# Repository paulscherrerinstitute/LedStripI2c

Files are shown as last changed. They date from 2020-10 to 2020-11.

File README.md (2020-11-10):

# Bar-Graph Display Project

Display current pulse-ID on a LED-bar.
The LEDs are driven by PCA9955 LED controllers
and remote-controlled by I2C over a fiber
connection.

 - [kicad/](kicad/)

   Kicad design files; [schematics](kicad/ledstrip-sch.pdf) and pcb.

 - [hdl/](hdl/)

   vhdl code for driving the device from a FPGA
   ([documentation](hdl/README.md)).

 - [python/](python/)

   python scripts to drive the device from the USB/I2C
   adapter (for testing).

 - [PulseidExtractor/](PulseidExtractor/)

   submodule required to extract the pulse-id from an EVR320
   stream.

The LED device's I2C bus is accessible by three methods:

 - optical (light <-> logic 'low' on I2C bus) 
 - PMOD connector (1.5-3.3 V via i2c-transceiver) for
   connection, e.g., to a Zynq board.
 - USB-I2c bridge from host.

Note that in all use-cases power (5V, 350mA max.) must be
provided at the USB port (from host or USB wall-wart).

A mini-USB connector was deemed mechanically more stable than
micro-USB. USB-C would be an alternative.

Till Straumann, 10/2020.

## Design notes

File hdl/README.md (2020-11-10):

# LedStrip Firmware

Extract the pulse-ID from a data stream (input) that 
originates at an embedded EVR320 module (the EVR320
is not instantiated within this LedStrip module).
Drive two PCA9955 LED controllers over i2c to display
the pulse-ID as a binary number (LED bar).

## Features

The firmware implements the following features:

 - tosca2/TCSR compatible register interface
 - controllable LED brightness.
 - programmable I2C speed.
 - readback verification: the firmware reads the displayed
   value back and increments an error counter if the readback
   does not match the expected value (catch potential i2c errors).
 - support permanently lit 'marker' LEDs.
 - display pulse-ID as gray-encoded or binary number.
 - error/status counters.

## Register Map (Version 0)

All registers are 32-bit. The address given in this table is
the register index (= word-address), not a byte address:

| Register | Access | Function |
|---|---|---|
|  0 | RO | Version Register |
|  1 | R/W | Control Register |
|  2 | R/W | Marker/Mask |
|  3 | RO | I2C Arbitration Lost Counter |
|  4 | RO | I2C Write Not Acknowledged Counter |
|  5 | RO | Readback Error/Mismatch Counter |
|  6 | RO | Pulse-Id Sequence Error Counter |
|  7 | RO | Pulse-Id Watchdog Error Counter |
|  8 | RO | Display-update Trigger Counter |
|  9 | RO | Stream Synchronization Error Counter |

The control register provides the following functionality
(Defaults marked with 'G' can be changed by setting a VHDL generic)

| Bit Range| Default | Function |
|---|---|---|
| [31:24]  | set for 400kHz (G)| Clock divider for generating SCL (see below) |
| [23:20]  | 0 | Multiplexer to select update trigger |
| [18] | 1 (G) | Enable Marker. |
| [17] | 0 | Enable binary encoding of display (Gray-code otherwise)|
| [16] | 0 | Reset firmware block (held in reset while bit is set)  |
| [15:08]  | 255 | Brightness PWM setting for PCA9955 |
| [07:00]  | 128 | Brightness IREF current setting for PCA9955 |

### Version Register
The least-significant 4 bits of the version register define the version
of the register layout (version 0 described in this document).
The most-significant 28 bits optionally contain a (binary-encoded) git
hash (all-zero when unused).

### Clock Divider

The i2c SCL clock is derived from the bus clock fed into the firmware module.

    SCL_clock = Bus_clock / divider_value / 4

The divider value is computed from the corresponding 8 bits in the control register.
If the most-significant bit of the divider value is set then bits [7:0] define the
divider value verbatim, e.g.,

    0xC0 => divider value 0x40 => SCL freq. = bus-freq / 64 / 4

If the MSbit is clear then the divider is taken from a table of larger values (consult
the firmware sources for details).

### Trigger Multiplexer

The firmware has 16 inputs for (Evr-generated) triggers which can be used to decimate
the rate at which the display updates (useful for slow cameras). The multiplexer selects
one of these triggers. By default trigger #0 is permanently asserted 1 (which results in
the display updating every time a new pulse-ID streams out of the EVR) and trigger #1 is
permanently asserted 0 (which results in the display not updating).

### Marker

If the marker is enabled then the displayed pulse-ID is shifted left by one bit and ORed
with a mask (contents of register R2):

    displayed_pattern :=  (pulse_id << 1) | mask

This feature can be used to permanently light some 'marker' LEDs. If the marker is disabled
then register R2 is ignored.

### Encoding

The pulse-ID can be displayed in binary- or gray-encoding. The latter has obvious advantages
when capturing the display with a camera. If exposure-time overlaps the change of the pulse-ID
then the relative brightness of the changing LED confers some information about the timing of
the shutter. It also avoids any ambiguity of a not properly synchronized readout.

### Reset

While this bit is asserted the firmware block (including the i2c controller) is held in reset.
Note that the reset does not extend to the remote PCA9955 LED controllers.

### PWM and IREF

The PCA9955 supports controlling LED brightness by two (cumulative) methods: PWM at a frequency
of multiple kHz as well as modulating an analog current source. Both parameters can be programmed
in the control register.

*NOTE*: The i2c transactions required to change the brightness are interleaved with updating
        the pulse-ID.  I.e., if the pulse-ID does not update (e.g., because the trigger mux
        selects the permanently disabled trigger) then the brightness settings are not forwarded
        to the PCA9955 controllers either. Similarly, if the update rate is reduced then changes
        to the brightness take longer to be forwarded to the PCA9955 (after each pulse-ID update
        *one* brightness setting for *one* LED is transmitted, e.g., it takes 64 pulse-ID updates
        to forward the PWM and IREF to all 32 channels in the PCA9955 devices).

### Error counters

The counters keep track of

 - Lost i2c arbitrations. Because normally (i.e., unless the USB-i2c bridge or the PMOD connector
   are in active use) there are no other bus masters these errors are most likely caused by too
   high a SCL frequency or non-optimal filter settings (only tunable via generics). Try lowering
   the i2c SCL frequency.
 - Unacknowledged i2c transactions. This occurs most likely because the LedStrip hardware module
   is not connected or intermediate entities (e.g., GPIO ports) are not configured correctly.
 - Readback errors. The readback failed or readback data does not match the expected value (e.g.,
   because a glitch on the i2c bus). An unacknowledged transaction error also implies a readback
   error but the converse is not true.
 - Pulse-Id sequence errors. This counter is incremented when the difference between
   subsequently received pulse-ids is not 1.
 - Watchdog errors: Check that a new pulse-ID is received from the EVR stream within 12 ms
   (this timeout value is a generic setting).
 - Trigger counter: This counter increments when the display update is triggered (which
   may happen at a rate that is lower than the pulse-Id update rate if the update trigger
   inputs are used).
 - EVR Stream Synchronization Errors. Checks that all bytes corresponding to a pulse-ID are
   actually received from the EVR stream. 

The readback error counter can be used to ensure that all pulse-IDs have been propagated
correctly to the display hardware. The watchdog error counter can be used to verify that
pulse-Ids are received and the sequence error counter can be used to verify that the
received pulse-Ids are sequential.

## Firmware Module

The top level entity is defined in [LedStripTcsrWrapper.vhd](LedStripTcsrWrapper.vhd).

### Dependencies

The module requires the [PulseidExtractor](https://github.com/paulscherrerinstitute/PulseIdExtractor.git)
which is registered as a submodule.

### Generics

Most of the generics have reasonable default values but a value for the bus frequency must
be supplied by the user.

| Generic |Default Value| Description |
|---|---|---|
|  TCSR_CLOCK_FRQ_G | | Bus Frequency (Hz) |
|  DFLT_I2C_SCL_FRQ_G | 400.0E3 | Default SCL Frequency (Hz) |
|  PULSEID_OFFSET_G | 52 | Starting offset of pulse-id in EVR stream |
|  PULSEID_LENGTH_G |  8 | Size of pulse-id (in bytes) |
|  PULSEID_BIGEND_G | false | Representation in EVR stream (big- vs. little-endian)|
|  ASYNC_CLOCKS_G | true | Whether the bus- and evr-clocks are asynchronous |
|  I2C_ADDR_R_G | "0000101" | I2C (7-bit) address of RHS PCA9955 |
|  I2C_ADDR_L_G | "1101001" | I2C (7-bit) address of LHS PCA9955 |
|  I2C_SYNC_STAGES_G | 3 | How many synchronizer stages on SCL/SDA inputs |
|  I2C_DEBOUNCE_CYCLES_G | 10 | For how many bus-cycles to debounce SCL/SDA inputs |
|  NUM_LEDS_G | 30 | How many LEDs are physically loaded on the board |
|  DFLT_MARKER_ENABLE_G  | '1' | Default value of marker-enable bit in R0 |
|  PULSEID_WDOG_PER_MS_G | 12.0 | Pulse-Id watchdog timeout [ms]; disabled when 0.0 |
|  VERSION_G | x"000_0000" | Firmware Version ID (e.g., git-hash) |

*Note*: The i2c addresses of the PCA9955 controllers is defined by hardware straps on the board
        but there are *slightly different versions of the PCA9955* which interpret the strapping
        differently (PCA9955 vs. PCA9955B). Consult the KiCad schematics and hardware manuals for
        details.

### Ports

The module's ports are listed in the following table. Signals are in the clock-domain of the last
clock previously listed.

|  Signal | Type/Default | Description |
|---|---|---|
|  tcsrCLK  | in  std_logic |  Bus clock |
|  tcsrRST  | in  std_logic |  Synchronous reset|
|  tcsrADD  | in  std_logic_vector( 4 downto 2) |  (Word-) address  |
|  tcsrDATW | in  std_logic_vector(31 downto 0) |  Write data |
|  tcsrWE | in  std_logic_vector( 3 downto 0) |  Lane write-enable|
|  tcsrDATR | out std_logic_vector(31 downto 0) |  Read data |
|  tcsrWR | in  std_logic |  Write strobe |
|  tcsrRD | in  std_logic |  Read strobe |
|  tcsrACK  | out std_logic |  ACK (always '1') |
|  tcsrERR  | out std_logic |  ERR (always '0') |
|  sclInp | in  std_logic |  i2c SCL input |
|  sclOut | out std_logic |  i2c SCL output |
|  sdaInp | in  std_logic |  i2c SDA input |
|  sdaOut | out std_logic |  i2c SDA output |
|  evrClk | in  std_logic |  EVR clock |
|  evrStream| in  EvrStreamType |  EVR data stream  |
|  ledTrig  | in  std_logic_vector(15 downto 0) := x"0001" |  Update trigger |

### Constraints

If the bus- and evr- clocks are asynchronous then some details need to be
considered: There are two clock-domain crossings in the module

 - The pulse-ID is taken from the `evrClk` into the `tcsrCLK` domain. If the
   `ASYNC_CLOCKS_G` generic is set to `true` then a synchronizer stage is
   instantiated which synchronizes and delays the pulse-ID strobe signal until
   the (parallel) pulse-ID has stabilized and can be safely read into the `tcslCLK`
   domain. A proper `DATAPATHONLY` constraint should be defined:

       INST "*B_PulseIdExtractor.U_GetPid/rClk_pulseid_*" TNM = LEDSTRIP_PULSEID_REG;
       TIMESPEC TS_<name> = FROM "LEDSTRIP_PULSEID_REG" TO <tnm_of_bus_clock_domain> <delay> DATAPATHONLY;

   The user has to provide proper definitions for the items in angled-brackets. The
   maximum datapath delay should limit any delay to less than the two bus-cycles delay
   of the strobe signal. Some margin needs to allocated to possible clock skew!

 - The trigger multiplexer setting crosses from the `tcsrCLK` into the `evrCLK` domain.
   Assuming that this setting remains mostly stable and we don't care about glitches
   during a change of the mux setting we can set a false-path:

       INST "*B_PulseIdExtractor.trgMuxEvr_*"          TNM = LEDSTRIP_MUX_REG;
       TIMESPEC TS_<name> = FROM <tnm_of_bus_clock_domain> TO "LEDSTRIP_MUX_REG" TIG;

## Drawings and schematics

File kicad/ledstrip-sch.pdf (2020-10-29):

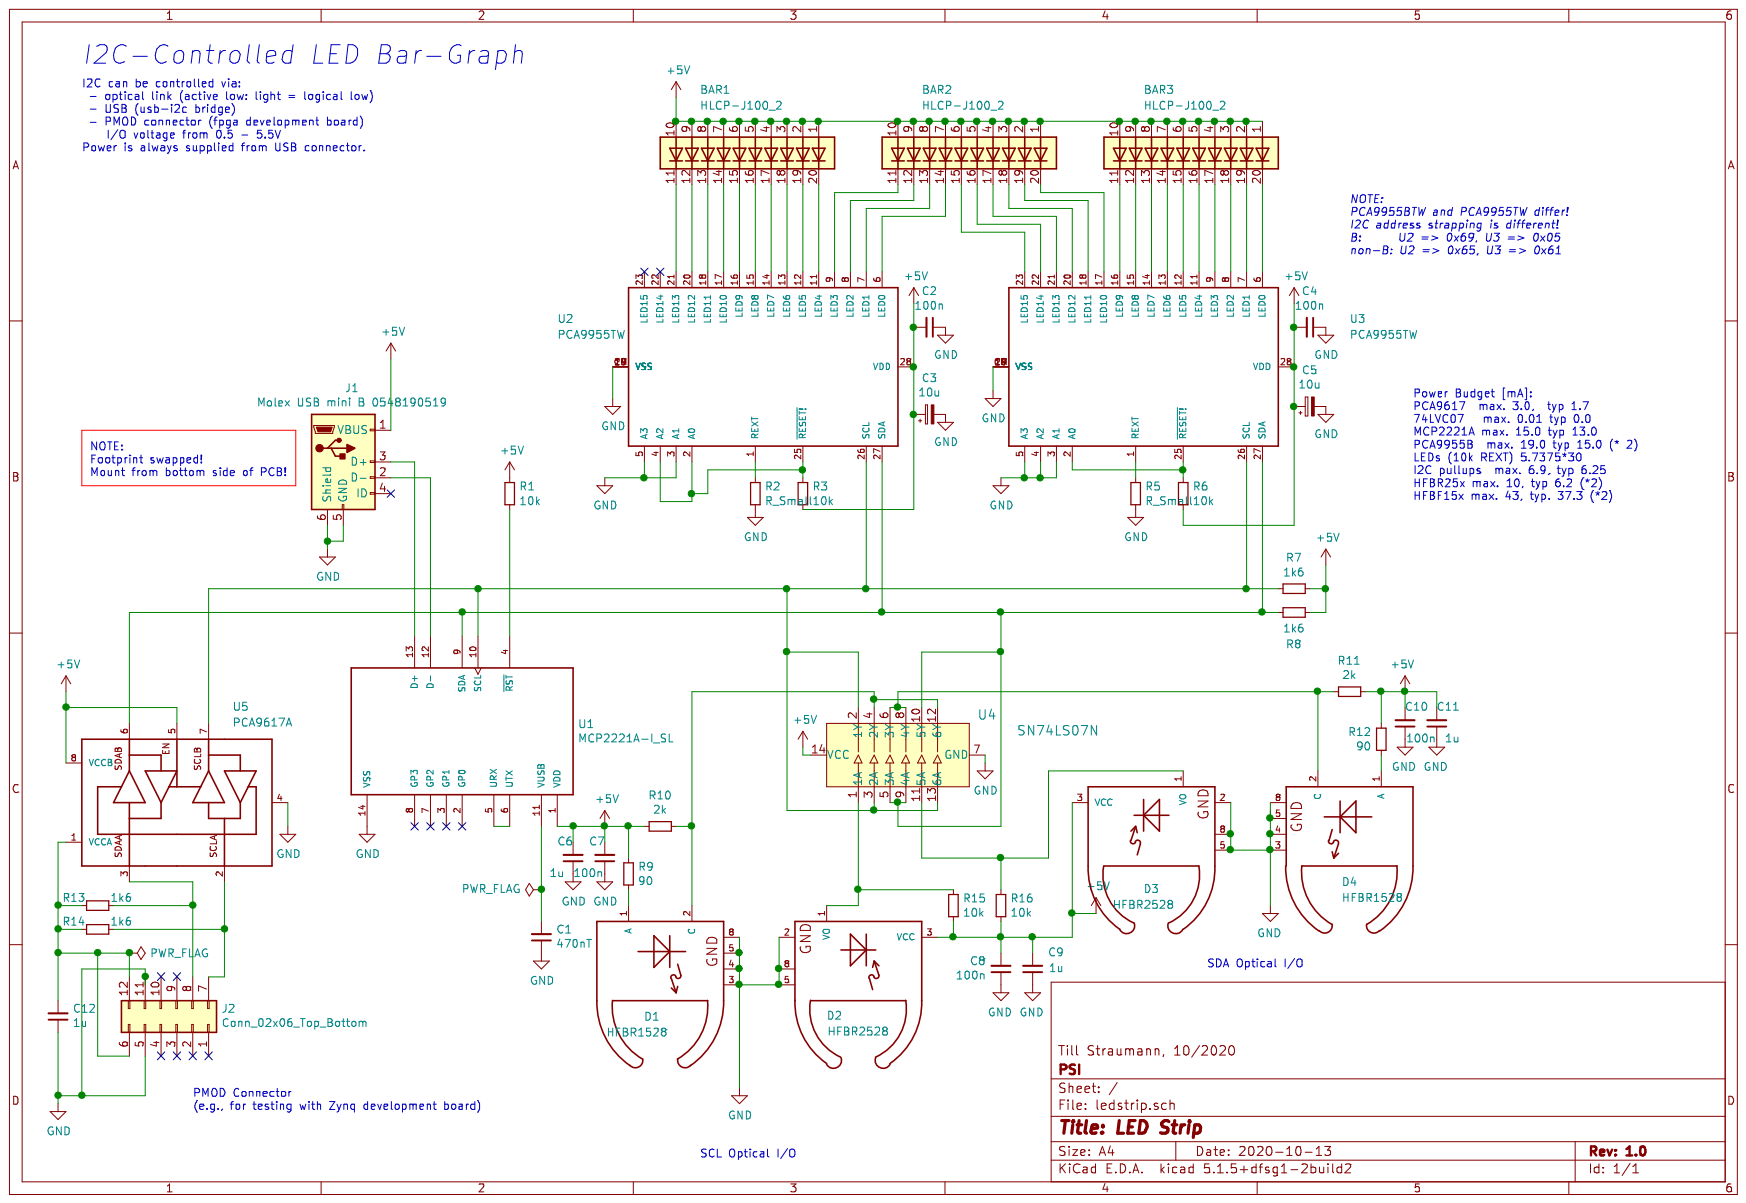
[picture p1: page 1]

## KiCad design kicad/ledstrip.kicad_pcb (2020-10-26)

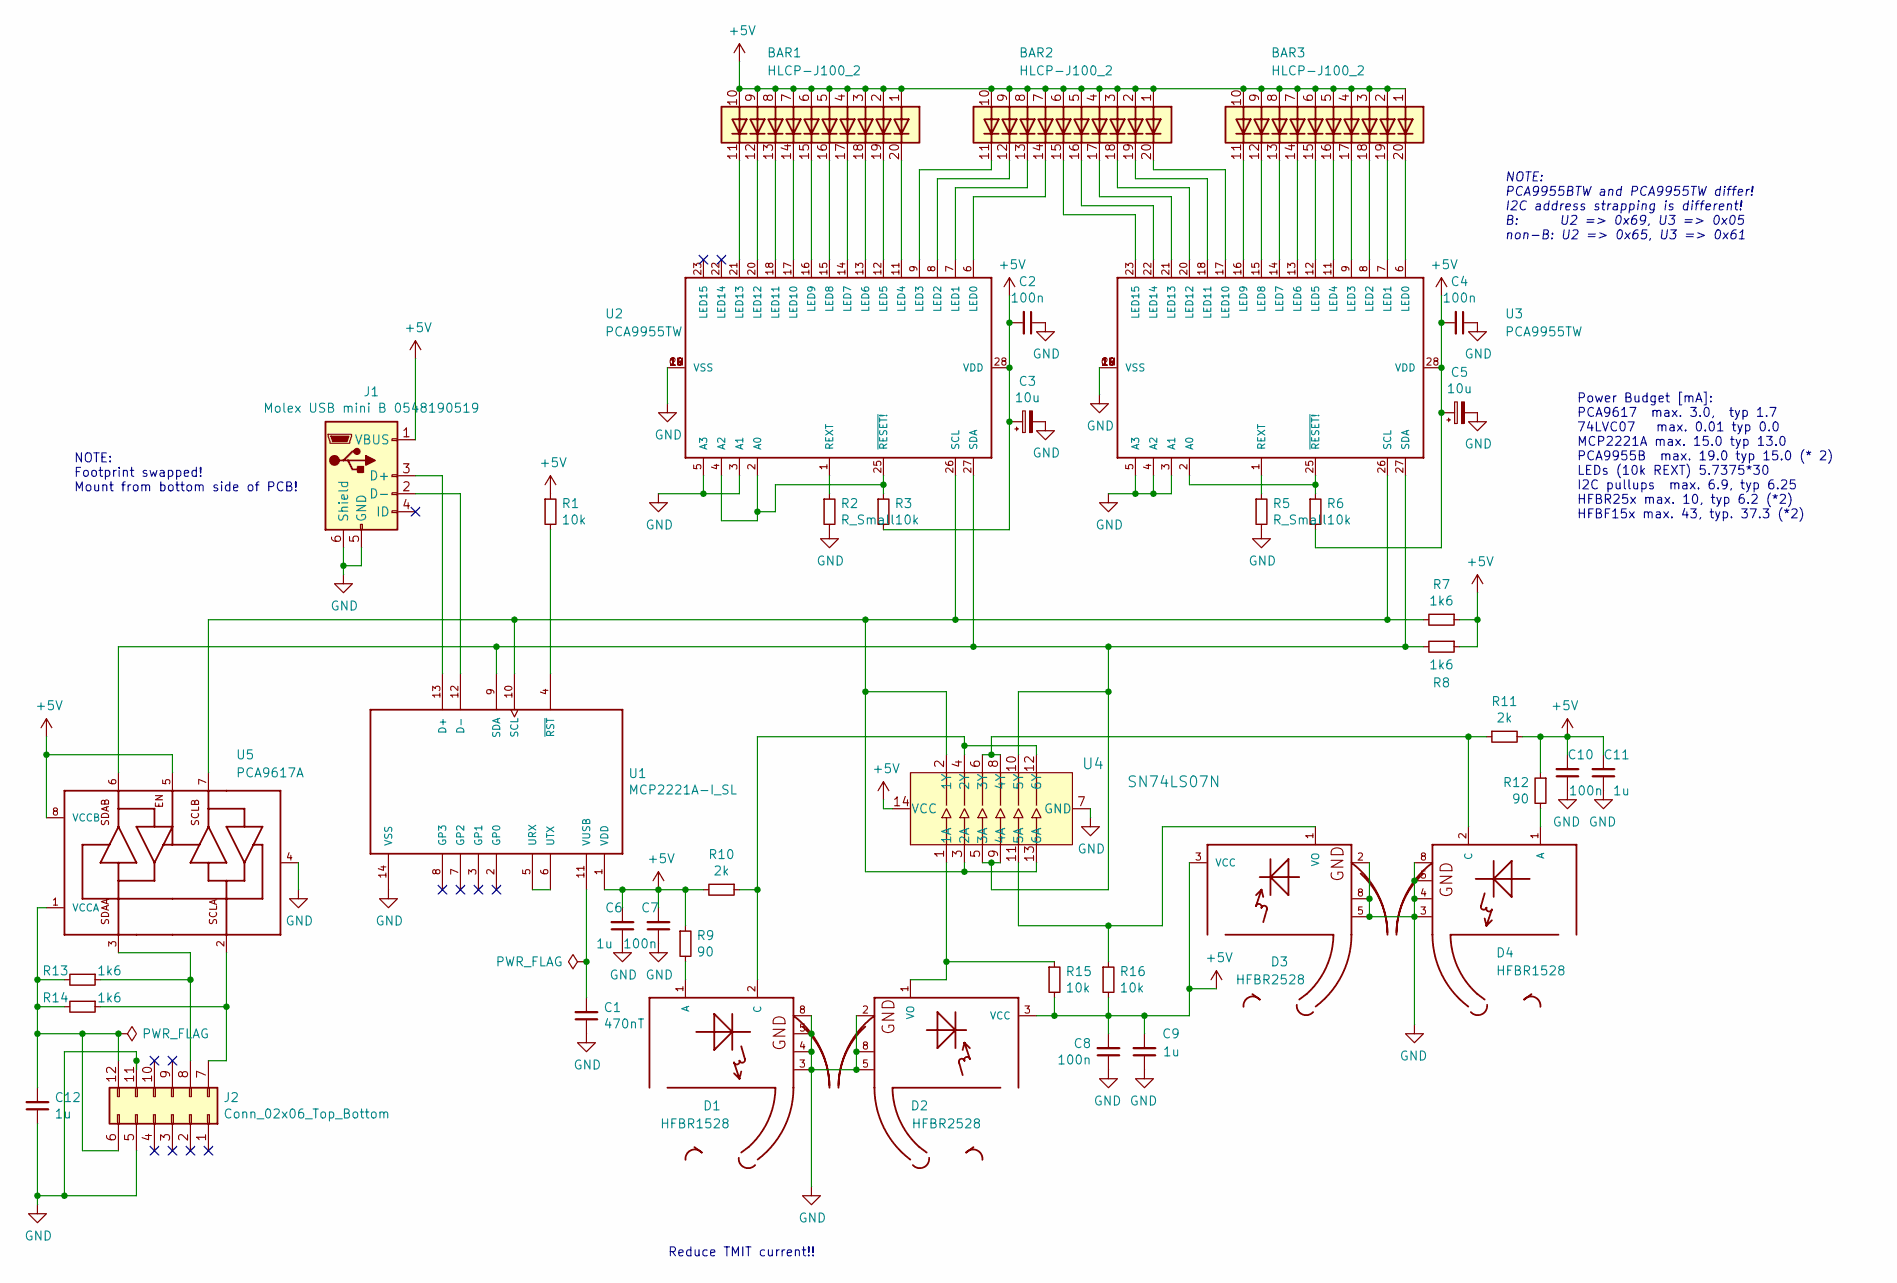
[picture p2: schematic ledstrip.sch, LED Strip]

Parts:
BAR1, BAR2, BAR3: HLCP-J100_2; HLCP-J100
C1: 470nT; C_0805_2012Metric
C2, C4, C7, C8, C10: 100n; C_0603_1608Metric
C3, C5: 10u; CP_EIA-3216-10_Kemet-I
C6, C9, C11, C12: 1u; C_0805_2012Metric
D1, D4: HFBR1528; HFBR25XX
D2, D3: HFBR2528; HFBR25XX
J1: Molex USB mini B 0548190519; USB_Mini_B_Female_548190519
J2: Conn_02x06_Top_Bottom; PMOD_PinHeader_2x06_P2.54mm_Horizontal
R1, R3, R6, R15, R16: 10k; R_0603_1608Metric
R2, R5: R_Small; R_0603_1608Metric
R7, R8, R13, R14: 1k6; R_0603_1608Metric
R9, R12: 90; R_1206_3216Metric
R10, R11: 2k; R_0603_1608Metric
U1: MCP2221A-I_SL; SOIC127P600X175-14N
U2, U3: PCA9955TW; SOT1172-2
U4: SN74LS07N; SOIC-14_3.9x8.7mm_P1.27mm; MPN SN74LS07N; Digi-Key_PN 296-1629-5-ND
U5: PCA9617A; TSSOP-8_W3mm

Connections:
+5V: BAR1.1 (A), BAR1.2 (A), BAR1.3 (A), BAR1.4 (A), BAR1.5 (A), BAR1.6 (A), BAR1.7 (A), BAR1.8 (A), BAR1.9 (A), BAR1.10 (A), BAR2.1 (A), BAR2.2 (A), BAR2.3 (A), BAR2.4 (A), BAR2.5 (A), BAR2.6 (A), BAR2.7 (A), BAR2.8 (A), BAR2.9 (A), BAR2.10 (A), BAR3.1 (A), BAR3.2 (A), BAR3.3 (A), BAR3.4 (A), BAR3.5 (A), BAR3.6 (A), BAR3.7 (A), BAR3.8 (A), BAR3.9 (A), BAR3.10 (A), C2.2, C3.1, C4.2, C5.1, C6.2, C7.2, C8.2, C9.2, C10.2, C11.2, D2.3 (VCC), D3.3 (VCC), J1.1 (VBUS), R1.1, R3.2, R6.2, R7.1, R8.1, R9.1, R10.2, R11.2, R12.1, R15.2, R16.2, U1.1 (VDD), U2.28 (VDD), U3.28 (VDD), U4.14 (VCC), U5.5, U5.8 (VCCB)
GND: C1.1, C2.1, C3.2, C4.1, C5.2, C6.1, C7.1, C8.1, C9.1, C10.1, C11.1, C12.1, D1.3, D1.4, D1.5, D1.8, D2.2, D2.5, D2.8, D3.2, D3.5, D3.8, D4.3, D4.4, D4.5, D4.8, J1.5 (GND), J1.6 (Shield), J2.5, J2.11, R2.2, R5.2, U1.14 (VSS), U2.3 (A1), U2.5 (A3), U2.10 (VSS), U2.19 (VSS), U2.24 (VSS), U2.CM (VSS), U3.3 (A1), U3.4 (A2), U3.5 (A3), U3.10 (VSS), U3.19 (VSS), U3.24 (VSS), U3.CM (VSS), U4.7 (GND), U5.4
unnamed: BAR1.11 (K), U2.21 (LED13)
unnamed: BAR1.12 (K), U2.20 (LED12)
unnamed: BAR1.13 (K), U2.18 (LED11)
unnamed: BAR1.14 (K), U2.17 (LED10)
unnamed: BAR1.15 (K), U2.16 (LED9)
unnamed: BAR1.16 (K), U2.15 (LED8)
unnamed: BAR1.17 (K), U2.14 (LED7)
unnamed: BAR1.18 (K), U2.13 (LED6)
unnamed: BAR1.19 (K), U2.12 (LED5)
unnamed: BAR1.20 (K), U2.11 (LED4)
unnamed: BAR2.11 (K), U2.9 (LED3)
unnamed: BAR2.12 (K), U2.8 (LED2)
unnamed: BAR2.13 (K), U2.7 (LED1)
unnamed: BAR2.14 (K), U2.6 (LED0)
unnamed: BAR2.15 (K), U3.23 (LED15)
unnamed: BAR2.16 (K), U3.22 (LED14)
unnamed: BAR2.17 (K), U3.21 (LED13)
unnamed: BAR2.18 (K), U3.20 (LED12)
unnamed: BAR2.19 (K), U3.18 (LED11)
unnamed: BAR2.20 (K), U3.17 (LED10)
unnamed: BAR3.11 (K), U3.16 (LED9)
unnamed: BAR3.12 (K), U3.15 (LED8)
unnamed: BAR3.13 (K), U3.14 (LED7)
unnamed: BAR3.14 (K), U3.13 (LED6)
unnamed: BAR3.15 (K), U3.12 (LED5)
unnamed: BAR3.16 (K), U3.11 (LED4)
unnamed: BAR3.17 (K), U3.9 (LED3)
unnamed: BAR3.18 (K), U3.8 (LED2)
unnamed: BAR3.19 (K), U3.7 (LED1)
unnamed: BAR3.20 (K), U3.6 (LED0)
unnamed: C1.2, U1.11 (VUSB)
unnamed: C12.2, J2.6, J2.12, R13.2, R14.2, U5.1 (VCCA)
unnamed: D1.1 (A), R9.2
unnamed: D1.2 (C), R10.1, U4.4 (2Y), U4.12 (6Y)
unnamed: D2.1 (VO), R15.1, U4.1 (1A)
unnamed: D3.1 (VO), R16.1, U4.11 (5A)
unnamed: D4.1 (A), R12.2
unnamed: D4.2 (C), R11.1, U4.6 (3Y), U4.8 (4Y)
unnamed: J1.2 (D-), U1.12 (D-)
unnamed: J1.3 (D+), U1.13 (D+)
unnamed: J2.7, R14.1, U5.2
unnamed: J2.8, R13.1, U5.3
unnamed: R1.2, U1.4 (~RST~)
unnamed: R2.1, U2.1 (REXT)
unnamed: R3.1, U2.2 (A0), U2.4 (A2), U2.25 (~RESET!~)
unnamed: R5.1, U3.1 (REXT)
unnamed: R6.1, U3.2 (A0), U3.25 (~RESET!~)
unnamed: R7.2, U1.10 (SCL), U2.26 (SCL), U3.26 (SCL), U4.2 (1Y), U4.3 (2A), U4.13 (6A), U5.7
unnamed: R8.2, U1.9 (SDA), U2.27 (SDA), U3.27 (SDA), U4.5 (3A), U4.9 (4A), U4.10 (5Y), U5.6
unnamed: U1.5 (URX), U1.6 (UTX)

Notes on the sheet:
Reduce TMIT current!!
Power Budget [mA]: PCA9617 max. 3.0, typ 1.7 74LVC07 max. 0.01 typ 0.0 MCP2221A max. 15.0 typ 13.0 PCA9955B max. 19.0 typ 15.0 (* 2) LEDs (10k REXT) 5.7375*30 I2C pullups max. 6.9, typ 6.25 HFBR25x max. 10, typ 6.2 (*2) HFBF15x max. 43, typ. 37.3 (*2)
NOTE: PCA9955BTW and PCA9955TW differ! I2C address strapping is different! B: U2 => 0x69, U3 => 0x05 non-B: U2 => 0x65, U3 => 0x61
NOTE: Footprint swapped! Mount from bottom side of PCB!

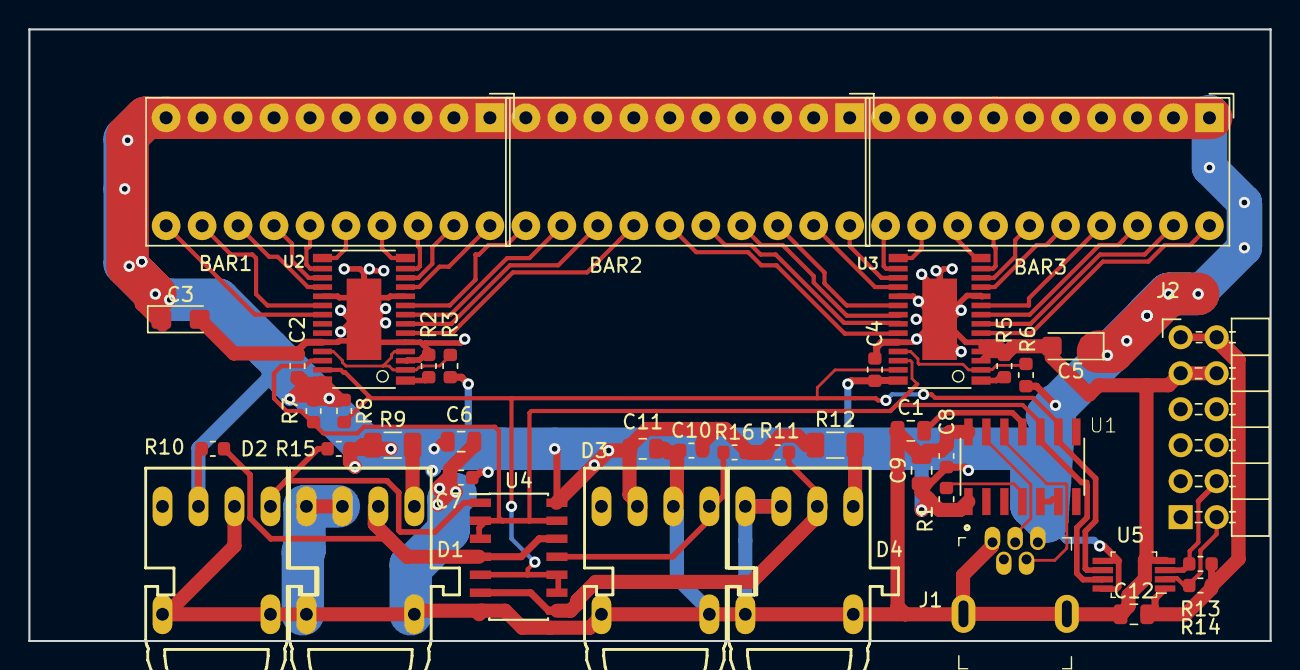
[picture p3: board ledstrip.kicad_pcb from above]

Board: 2 copper layers, 87.6 x 43.2 mm, 41 parts (0 on the bottom side), 52 nets.

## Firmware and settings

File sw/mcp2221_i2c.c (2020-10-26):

/* User-space 'driver' for Microchip MPC 2221A usb-i2c bridge
 */

#include <stdio.h>
#include <stdlib.h>
#include <libusb-1.0/libusb.h>
#include <inttypes.h>
#include <assert.h>
#include <string.h>
#include <stdarg.h>
#include <time.h>

struct Mcp2221Buf {
	uint8_t                  b[64];
};

struct ErrfnCtx {
	FILE *f;
};

typedef int (*Errfn)(struct ErrfnCtx *, const char *, ...);

struct mcp2221_dev {
    libusb_context          *ctx;
    libusb_device_handle    *devh;
    int                      rendp;
    int                      wendp;
    int                      intf;
	int                      dir;
	unsigned int             timeout_ms;
    Errfn                    errfn;
    struct ErrfnCtx         *errfp;
};


#define MICROCHIP_VENDID 0x04d8
#define MCP2221_DEVID    0x00dd

#define DIR_WR 1

#define MCP2221_SYSFREQ  12000000UL

#define AUTO_INC         0x80

static struct mcp2221_dev *devalloc()
{
struct mcp2221_dev *rval = malloc(sizeof(*rval));
	if ( rval ) {
		rval->ctx   =  0;
		rval->devh  =  0;
		rval->dir   = DIR_WR;
		rval->rendp = -1;
		rval->wendp = -1;
		rval->intf  = -1;
	}
	return rval;
}

void
mcp2221_dev_destroy(struct mcp2221_dev *dev)
{
	if ( !dev )
		return;

	if ( dev->devh && dev->intf >= 0 )
		libusb_release_interface( dev->devh, dev->intf );

	if ( dev->devh ) {
		libusb_close( dev->devh );
	}

	if ( dev->ctx )
		libusb_exit( dev->ctx );

	free(dev);
}

static int
errfn_silent(struct ErrfnCtx *errfnp, const char *fmt, ...)
{
	return 0;
}

static int
errfn_stderr(struct ErrfnCtx *ctx, const char *fmt, ...)
{
va_list ap;
int    rval;

	va_start(ap, fmt);
		rval = vfprintf(ctx->f ? ctx->f : stderr, fmt, ap);
	va_end(ap);

    return rval;
}

static struct ErrfnCtx errfnToStderr = {
  f : 0,
};

static struct ErrfnCtx *errfp_stderr = &errfnToStderr;

struct mcp2221_dev *
mcp2221_dev_create_1(int verbose, uint16_t vid, uint16_t pid, Errfn errfn, struct ErrfnCtx *errfp, unsigned int timeout_ms)
{
struct mcp2221_dev                          *rval = 0;
struct libusb_config_descriptor              *cfg = 0;
int                              i, l, hask, st;
struct mcp2221_dev                         *dev;
const struct libusb_endpoint_descriptor      *e;

	if ( ! (dev = devalloc()) ) {
		errfn(errfp, "No memory for device struct\n");
		return 0;
	}

	dev->timeout_ms = timeout_ms;

	if ( libusb_init( &dev->ctx ) ) {
		errfn(errfp, "Context init failed\n");
		goto bail;
	}

	if ( vid && pid ) {
		if ( ! (dev->devh = libusb_open_device_with_vid_pid( dev->ctx, vid, pid) ) ) {
			errfn(errfp, "Unable to find device 0x%04x:0x%04x\n", vid, pid);
			goto bail;
		}
	} else {
		errfn(errfp, "Missing VENDOR_ID or PRODUCT_ID\n");
		goto bail;
	}

	if ( libusb_get_active_config_descriptor( libusb_get_device( dev->devh ), &cfg ) ) {
		errfn(errfp, "Unable to get active configuration\n");
		goto bail;
	}

	for ( i = 0; i < cfg->bNumInterfaces; i++ ) {

		/* FIXME: should we care about altsettings? */

		if ( LIBUSB_CLASS_HID == cfg->interface[i].altsetting[0].bInterfaceClass ) {
			hask = libusb_kernel_driver_active( dev->devh, i );
			if ( verbose ) {
				printf("Interface (CLASS HID) #%i has %s active kernel driver\n", i, hask ? "a" : "no");
			}
			if ( hask ) {
				if ( (st = libusb_detach_kernel_driver( dev->devh, i )) ) {
					errfn(errfp, "Unable to detach kernel driver (interface #%i): %i\n", i, st);
					goto bail;
				} else {
					if ( verbose )
						printf("Kernel driver successfully detached\n");
				}
			}

			e = cfg->interface[i].altsetting[0].endpoint;

			for ( l = 0; l < cfg->interface[i].altsetting[0].bNumEndpoints; l++, e++ ) {
				if ( LIBUSB_TRANSFER_TYPE_INTERRUPT != (LIBUSB_TRANSFER_TYPE_MASK & e->bmAttributes) )
					continue;

				if ( (LIBUSB_ENDPOINT_DIR_MASK & e->bEndpointAddress) ) {
					if ( dev->rendp >= 0 ) {
						errfn(errfp, "Error: Multiple IN endpoints???\n");
						goto bail;
					}
					dev->rendp = e->bEndpointAddress;
				} else {
					if ( dev->wendp >= 0 ) {
						errfn(errfp, "Error: Multiple OUT endpoints???\n");
						goto bail;
					}
					dev->wendp = e->bEndpointAddress;
				}
			}
			break;
		}
	}

	if ( dev->rendp < 0 ) {
		errfn(errfp, "Unable to determine IN endpoint!\n");
		goto bail;
	}
	if ( dev->wendp < 0 ) {
		errfn(errfp, "Unable to determine OUT endpoint!\n");
		goto bail;
	}

	assert( i < cfg->bNumInterfaces );

	dev->intf = cfg->interface[i].altsetting[0].bInterfaceNumber;

	if ( verbose )
		printf("Using intf %u / endpoints: IN - 0x%02x OUT - 0x%02x\n", dev->intf, dev->rendp, dev->wendp);
	if ( (st = libusb_claim_interface( dev->devh, dev->intf ) ) ) {
		errfn(errfp, "Unable to claim interface %u: %i\n", dev->intf, st);
		goto bail;
	}

	dev->errfn = errfn;
	dev->errfp = errfp;

	/* initially, we don't know if the last operation was
	 * read or write since it may have happened before our
	 * life-time...
	 */
	dev->dir   = DIR_WR;

	rval = dev;
	dev  = 0;

bail:

	if ( cfg ) {
		libusb_free_config_descriptor( cfg );
	}

	mcp2221_dev_destroy( dev );

	return rval;
}

struct mcp2221_dev *
mcp2221_dev_create(int verbose, uint16_t vid, uint16_t pid)
{
	return mcp2221_dev_create_1( verbose, vid, pid, errfn_stderr, errfp_stderr, -1 );
}

static int
mcp2221_xfer(struct mcp2221_dev *dev, struct Mcp2221Buf *ibuf, struct Mcp2221Buf *obuf)
{
int st, put, got;

	if ( ! obuf ) {
		obuf = ibuf;
	}

	if ( (st = libusb_interrupt_transfer( dev->devh, dev->wendp, ibuf->b, sizeof(ibuf->b), &put, dev->timeout_ms)) ) {
		dev->errfn(dev->errfp, "mcp2221_xfer: WRITE XFER failed: %i\n", st);
		return st;
	}

	if ( put != sizeof(ibuf->b) ) {
		dev->errfn(dev->errfp, "mcp2221_xfer: WRITE XFER failed -- not all data written (only %i)\n", put);
		return LIBUSB_ERROR_IO;
	}

	if ( (st = libusb_interrupt_transfer( dev->devh, dev->rendp, obuf->b, sizeof(obuf->b), &got, dev->timeout_ms)) ) {
		dev->errfn(dev->errfp, "mcp2221_xfer: READ XFER failed: %i\n", st);
		return st;
	}

	if ( got != sizeof(obuf->b) ) {
		dev->errfn(dev->errfp, "mcp2221_xfer: READ XFER failed -- not all data read (only %i)\n", got);
		return LIBUSB_ERROR_IO;
	}

	return 0;
}

int
mcp2221_status_get(struct mcp2221_dev *dev, struct Mcp2221Buf *buf, int cancel, unsigned long speed)
{
int               st;
struct Mcp2221Buf mybuf;

	if ( !buf ) {
		buf = &mybuf;
	}

	buf->b[0] = 0x10;
	buf->b[1] = 0x00;
	buf->b[2] = (cancel ? 0x10 : 0x00);
	buf->b[3] = (speed  ? 0x20 : 0x00);
    buf->b[4] = (speed  ? MCP2221_SYSFREQ / speed : 0x00 );

	if ( (st = mcp2221_xfer( dev, buf, buf )) ) {
		dev->errfn(dev->errfp, "mcp2221_status_get(): transfer failed\n");
		return st;
	}
	return 0;
}

int
mcp2221_status(struct mcp2221_dev *dev, int cancel, unsigned long speed)
{
struct Mcp2221Buf buf;
int               st;


	if ( (st = mcp2221_status_get( dev, &buf, cancel, speed )) ) {
		dev->errfn(dev->errfp, "mcp2221_status(): transfer failed\n");
		return st;
	}

	printf("Current data buf cntr: %u\n", buf.b[13]);
	printf("Current speed divider: %u\n", buf.b[14]);
	printf("Current i2c timeout  : %u\n", buf.b[15]);
	printf("Current SCL pin value: %u\n", buf.b[22]);
	printf("Current SDA pin value: %u\n", buf.b[23]);
	printf("Current i2c r-pending: %u\n", buf.b[25]);

	return 0;
}

static int
mcp2221_drain(struct mcp2221_dev *dev)
{
struct Mcp2221Buf buf;
int               st;
	do {

		if ( (st = mcp2221_status_get(dev, &buf, 0, 0)) ) {
			return st;
		}

	} while ( buf.b[13] != 0 );
	
	return 0;
}

int
mcp2221_start_write(struct mcp2221_dev *dev, uint8_t sla, uint8_t *data, unsigned len, int stop)
{
struct Mcp2221Buf buf;
int               st;

	if ( len > 60 ) {
		dev->errfn( dev->errfp, "mcp2221_start_write(): Writing more than 60 bytes currently not supported\n");
		return LIBUSB_ERROR_INVALID_PARAM;
	}

	buf.b[0] = (stop ? 0x90 : 0x94);
	buf.b[1] = (len >> 0) & 0xff;
	buf.b[2] = (len >> 8) & 0xff;
    buf.b[3] = (sla<<1);
	if ( len > 0 ) {
		memcpy(buf.b + 4, data, len);
	}

	if ( (st = mcp2221_xfer(dev, &buf, &buf)) ) {
		dev->errfn( dev->errfp, "mcp2221_start_write(): transfer failed\n");
		return st;
	}

	if ( 0x00 != buf.b[1] ) {
		dev->errfn( dev->errfp, "mcp2221_start_write(): transfer failed (I2C was busy)\n");
		return LIBUSB_ERROR_BUSY;
	}
	

}

int
mcp2221_start_read(struct mcp2221_dev *dev, uint8_t sla, uint8_t *data, unsigned len, int restart)
{
struct Mcp2221Buf buf;
int               st;

	if ( len > 60 ) {
		dev->errfn( dev->errfp, "mcp2221_start_read(): Writing more than 60 bytes currently not supported\n");
		return LIBUSB_ERROR_INVALID_PARAM;
	}

	buf.b[0] = (restart ? 0x93 : 0x91);
	buf.b[1] = (len >> 0) & 0xff;
	buf.b[2] = (len >> 8) & 0xff;
    buf.b[3] = (sla<<1) | 1;

	if ( (st = mcp2221_xfer(dev, &buf, &buf)) ) {
		dev->errfn( dev->errfp, "mcp2221_start_read(): command transfer failed\n");
		return st;
	}

	if ( 0x00 != buf.b[1] ) {
		dev->errfn( dev->errfp, "mcp2221_start_read(): transfer failed (I2C was busy)\n");
		return LIBUSB_ERROR_BUSY;
	}

	mcp2221_drain(dev);

	buf.b[0] = 0x40;

	if ( (st = mcp2221_xfer(dev, &buf, &buf)) ) {
		dev->errfn( dev->errfp, "mcp2221_start_read(): readout transfer failed\n");
		return st;
	}

	if ( 0x00 != buf.b[1] || 60 < buf.b[3] ) {
		fprintf(stderr, "buf[1]: 0x%02x, buf[3]: 0x%02x\n", buf.b[1], buf.b[3]);
		dev->errfn( dev->errfp, "mcp2221_start_read(): readout error\n");
		return LIBUSB_ERROR_IO;
	}
	
	if ( len > buf.b[3] ) {
		len = buf.b[3];
	}
	memcpy(data, buf.b + 4, len);
	return len;
}

#if 0

static int
mcp2221_i2c_wr( cy32xx_dev *dev , uint8_t sla, uint8_t *buf, unsigned len )
{
int st, put;

	if ( 4 != sla ) {
		dev->errfn(dev->errfp, "Slave address must be 4\n");
		return CY32XX_INVALID_SLA;
	}

	if ( (st = libusb_interrupt_transfer( dev->devh, dev->wendp, buf, len, &put, dev->timeout_ms)) ) {
		dev->errfn(dev->errfp, "WRITE XFER failed: %i\n", st);
		return st;
	}

	dev->dir = DIR_WR;
	return put;
}

static int
mcp2221_rd( cy32xx_dev *dev , uint8_t sla, uint8_t *buf, unsigned len )
{
int     st, got;
uint8_t dbuf[1];

	if ( 4 != sla ) {
		dev->errfn(dev->errfp, "Slave address must be 4\n");
		return CY32XX_INVALID_SLA;
	}

	if ( len > 16 ) {
		/* cy3270 can only read 16 bytes at a time */
		len = 16;
	}

	if ( DIR_RD != dev->dir ) {
		/* Do 'dummy' read -- seems necessary to make changes visible with next 'real' read */
		if ( (st = libusb_interrupt_transfer( dev->devh, dev->rendp, dbuf, sizeof(dbuf), &got, dev->timeout_ms) ) ) {
			dev->errfn(dev->errfp, "WRITE XFER Dummy read failed: %i\n", st);
			return st;
		}
		dev->dir = DIR_RD;
	}

	if ( (st = libusb_interrupt_transfer( dev->devh, dev->rendp, buf, len, &got, dev->timeout_ms)) ) {
		dev->errfn(dev->errfp, "READ XFER failed: %i\n", st);
		return st;
	}
	return got;
}

int
cy32xx_read( cy32xx_dev *dev , uint8_t sla, uint8_t *buf, unsigned len )
{
	return dev->ops->read( dev, sla, buf, len );
}

int
cy32xx_write( cy32xx_dev *dev , uint8_t sla, uint8_t *buf, unsigned len )
{
	return dev->ops->write( dev, sla, buf, len );
}

#define CY3240_CTRL_READ  (1<<0)	/* Read    */
#define CY3240_CTRL_STRT  (1<<1)	/* Start   */
#define CY3240_CTRL_REST  (1<<2)	/* Restart */
#define CY3240_CTRL_STOP  (1<<3)	/* Stop    */
#define CY3240_CTRL_INIT  (1<<4)	/* Init    */
#define CY3240_CTRL_CNFG  (1<<5)	/* Config  */
#define CY3240_CTRL_TI2C  (0<<6)	/* Bustype */

#define CY3240_CTRL_CFG_SPEED_50	(2<<2)
#define CY3240_CTRL_CFG_SPEED_100	(0<<1)
#define CY3240_CTRL_CFG_SPEED_400	(1<<2)

#define CY3240_LENG_MORE        0x80

#define CY3240_INTRN_SLA		0x80	/* Slave address for internal operation */
#define CY3240_INTRN_PWR_EXT	0
#define CY3240_INTRN_PWR_5V 	1
#define CY3240_INTRN_PWR_3V 	2

#define CY3240_BUFLEN           64

#define CY3240_CTRL_OFF			0
#define CY3240_STAT_OFF			0
#define CY3240_LENG_OFF			1
#define CY3240_RSLT_OFF			1
#define CY3240_ADDR_OFF			2
#define CY3240_DATA_OFF			3

#define CY3240_LEN_MAX         61


static int cy3240_check( const char *nm, cy32xx_dev *dev )
{
	if ( CYPRESS_VENDID != dev->ops->vendid || CY3240_DEVID != dev->ops->devid ) {
		dev->errfn(dev->errfp, "%s called for unsupported device 0x%04"PRIx16"\n", nm, dev->ops->devid);
		return CY32XX_UNSUPPORTED;
	}
	return 0;
}


int
cy3240_config( cy32xx_dev *dev, uint8_t ctrl )
{
uint8_t buf[CY3240_BUFLEN];
int     st;
int     got,put;

	if ( (got = cy3240_check( "cy3240_config()", dev )) )
		return got;

	ctrl |= CY3240_CTRL_CNFG;

	buf[CY3240_CTRL_OFF] = ctrl;
	buf[CY3240_LENG_OFF] = 0;

	if ( (st = libusb_interrupt_transfer( dev->devh, dev->wendp, buf, sizeof(buf), &put, dev->timeout_ms)) ) {
		dev->errfn(dev->errfp, "WRITE XFER failed: %i\n", st);
		return st;
	}
	if ( (st = libusb_interrupt_transfer( dev->devh, dev->rendp, buf, sizeof(buf), &got, dev->timeout_ms) ) ) {
		dev->errfn(dev->errfp, "READ XFER failed: %i\n", st);
		return st;
	}
	if ( ! buf[CY3240_STAT_OFF] ) {
		dev->errfn(dev->errfp, "I2C Configuration returned with bad status %"PRIu8"\n", buf[CY3240_STAT_OFF]);
		return CY3240_BADCONFIGST;
	}
	return 1;
}

#define ERRBUFLEN 256
struct errfn_args {
	int     len;
	char    buf[];
};

static int
errfn_buf(cy32xx_errfn_param errfp, const char *fmt, ...)
{
va_list ap;
struct errfn_args *arg = (struct errfn_args*)errfp;
int    rval;

	va_start(ap, fmt);
		rval = vsnprintf(arg->buf, arg->len, fmt, ap );
	va_end(ap);
	return rval;
}

uint8_t *
cy32xx_scanbus( cy32xx_dev *dev )
{
uint8_t            buf[64];
uint8_t            sla, ctl;
uint8_t            *rval = 0;
int                st, k;
cy32xx_errfn       errfn_orig;
cy32xx_errfn_param errfp_orig;
struct errfn_args  *args = 0;

	ctl = CY3240_CTRL_STRT | CY3240_CTRL_STOP | CY3240_CTRL_READ;

	rval = malloc( sizeof(*rval) * 129 );

	args = malloc( sizeof(*args) + ERRBUFLEN );
	args->len = ERRBUFLEN;

	errfn_orig = dev->errfn;
	errfp_orig = dev->errfp;
	cy32xx_set_errfn( dev, errfn_buf, args );
	for ( sla = 0, k = 0; sla < 128; sla++ ) {
		if ( 0 == (st = cy32xx_read( dev, sla, buf, 0 )) ) {
			rval[k++] = sla;
		} else {
			if ( CY32XX_SLAVENOTFND != st ) {
				errfn_orig(errfp_orig, "%s", args->buf);
			}
		}
	}
	cy32xx_set_errfn( dev, errfn_orig, errfp_orig );
	free ( args );

	rval[k] = CY32XX_SLA_NONE;

	return rval;
}

#define SLA_NOSTART 0xffff

int
cy3240_xact( cy32xx_dev *dev, uint8_t rw, unsigned sla, uint8_t *dta, unsigned len )
{
uint8_t buf[CY3240_BUFLEN];
int     st;
int     put,got,i;
uint8_t ctrl;

	if ( (got = cy3240_check( "cy3240_xact()", dev )) )
		return got;

	if ( len > CY3240_LEN_MAX ) {
		dev->errfn(dev->errfp, "Requested transfer length > %u not supported; clamping...\n", CY3240_LEN_MAX);
		len = CY3240_LEN_MAX;
	}

	ctrl = 0;
	
	if ( sla != SLA_NOSTART )
		ctrl |= CY3240_CTRL_STRT;
	if ( dta )
		ctrl |= CY3240_CTRL_STOP;

	if ( rw ) {
		ctrl |= CY3240_CTRL_READ;
	} else {
		if ( dta )
			memcpy( &buf[CY3240_DATA_OFF], dta, len );
	}

	buf[CY3240_CTRL_OFF] = ctrl;
	buf[CY3240_LENG_OFF] = len;
	buf[CY3240_ADDR_OFF] = SLA_NOSTART == sla ? /* should't' matter */ 0 : sla;

printf("Writing...\n");
	if ( (st = libusb_interrupt_transfer( dev->devh, dev->wendp, buf, sizeof(buf), &put, dev->timeout_ms)) ) {
		dev->errfn(dev->errfp, "WRITE XFER failed: %i\n", st);
		return st;
	}

printf("Done.\nReading...\n");
	if ( (st = libusb_interrupt_transfer( dev->devh, dev->rendp, buf, sizeof(buf), &got, dev->timeout_ms) ) ) {
		dev->errfn(dev->errfp, "READ XFER failed: %i\n", st);
		return st;
	}
printf("Done.\n");

	if ( ! buf[CY3240_STAT_OFF] ) {
		dev->errfn(dev->errfp, "I2C Transfer failed with zero status (slave not found)\n");
		return CY32XX_SLAVENOTFND;
	}

	if ( rw ) {
		if ( dta )
			memcpy( dta, &buf[CY3240_RSLT_OFF], len );
	} else {
		for ( i=0; i<len-1; i++ ) {
			if ( !buf[CY3240_RSLT_OFF + i] ) {
				dev->errfn(dev->errfp, "I2C-Write: only %u bytes ACKed!\n", i);
				return i+1;
			}
		}
	}
	return len;
}

static int
cy3240_rd( cy32xx_dev *dev, uint8_t sla, uint8_t *buf, unsigned len )
{
	if ( sla > 127 ) {
		dev->errfn(dev->errfp, "cy3240_rd(): slave address must be < 128\n");
		return CY32XX_INVALID_SLA;
	}

	return cy3240_xact( dev, 1, sla, buf, len );
}

static int
cy3240_wr( cy32xx_dev *dev, uint8_t sla, uint8_t *buf, unsigned len )
{
	if ( sla > 127 ) {
		dev->errfn(dev->errfp, "cy3240_wr(): slave address must be < 128\n");
		return CY32XX_INVALID_SLA;
	}
	return cy3240_xact( dev, 0, sla, buf, len );
}

static int cy3240_in(cy32xx_dev *dev)
{
uint8_t dbuf[64];
int     st, got;
	/* By protocol-sniffing I found that this initial transfer is necessary
	 * in order to get the green light on the bridge to show and the
	 * thing to respond to further requests.
	 * Note that the transfer actually fails/times-out which we ignore...
	 */
	if ( (st = libusb_interrupt_transfer( dev->devh, dev->rendp, dbuf, sizeof(dbuf), &got, 100) ) ) {
#if 0
		dev->errfn(dev->errfp, "cy32xx_in: initial read failed: %i\n", st);
#endif
	}
	return 0;
}

#define CY3240_PWR(mode) (((mode)>>16) & 0xff)
#define CY3240_CLK(mode) (((mode)>> 8) & 0xff)
#define CY3240_MODE_VDEV	0x40
#define CY3240_MODE_INTP	0x20
#define CY3240_MODE_OK  	0x01

int
cy3240_mode_read( cy32xx_dev *dev )
{
uint8_t dta[2];
int     st;
	
	st = cy3240_xact( dev, 1, CY3240_INTRN_SLA, dta, sizeof(dta) );

	if ( st < 0 )
		return st;

	return (dta[0] << 16) | (dta[1] <<8) | st;
}

int
cy3240_pwr_set( cy32xx_dev *dev, uint8_t pwr )
{
int st;

	st = cy3240_xact( dev, 0, CY3240_INTRN_SLA, &pwr, 1 );

	return st < 0 ? st : 0;
}

const char *
cy32xx_get_desc( cy32xx_dev *dev )
{
	return dev->ops->desc;
}
#endif

int
mcp2221_rd_reg(struct mcp2221_dev *dev, uint8_t sla, uint8_t roff)
{
int st;
uint8_t val;

	if ( (st = mcp2221_start_write(dev, sla, &roff, 1, 0)) ) {
		return st;
	}
	if ( (st = mcp2221_start_read (dev, sla, &val, 1, 1)) < 0 ) {
		return st;
	}
	return val;
}

int
mcp2221_wr_reg(struct mcp2221_dev *dev, uint8_t sla, uint8_t roff, uint8_t val)
{
int     st;
uint8_t buf[2];

	buf[0] = roff;
	buf[1] = val;

	if ( (st = mcp2221_start_write(dev, sla, buf, sizeof(buf), 1)) ) {
		return st;
	}
	return 0;
}

static int
set_led(struct mcp2221_dev *dev, uint8_t sla, int led, uint8_t pwm, uint8_t iref)
{
int     f, t, st;
uint8_t pwreg = 0x08;
uint8_t irreg = 0x18;

	if ( led > 15 ) {
		return LIBUSB_ERROR_INVALID_PARAM;
	}

	if ( led < 0 ) {
		f = 0; t = 15;
	} else {
		f = t = led;
	}

	for ( ; f <= t; f++ ) {
		if ( (st = mcp2221_wr_reg( dev, sla, pwreg + f, pwm )) ) {
			dev->errfn(dev->errfp, "set_led: writing pwm (led %d) failed\n", f);
			return st;
		}
		if ( (st = mcp2221_wr_reg( dev, sla, irreg + f, iref )) ) {
			dev->errfn(dev->errfp, "set_led: writing pwm (led %d) failed\n", f);
			return st;
		}
	}

	return 0;
}

static int
set_led_ctl(struct mcp2221_dev *dev, uint8_t sla, uint16_t ctl)
{
uint8_t buf[5];
int     i;

	buf[0] = AUTO_INC | 0x02;

	for ( i = 0; i < 16; i++ ) {
		buf[ 1 + (i >> 2) ] &= ~ (3 << (2*(i & 3)));
		if ( ctl & (1<<i) ) {
			buf[ 1 + (i >> 2) ] |= (2 << (2*(i & 3)));
		}
	}

	return mcp2221_start_write( dev, sla, buf, sizeof(buf), 1 );
}

int
main(int argc, char **argv)
{
struct mcp2221_dev *dev = mcp2221_dev_create(1, MICROCHIP_VENDID, MCP2221_DEVID);
uint8_t             buf[60];
int                 got;
uint8_t             sla  = 0x69; /* 0x05, 0x69 */
uint8_t             addr = AUTO_INC | 0x00;
int                 i,j;
int                 rval   = 1;
struct timespec     wai;

uint8_t             slas[2] = {0x05, 0x69};

	if ( ! dev ) {
		return 1;
	}

 mcp2221_start_write( dev, sla, &addr, 1, 0 );
    got = mcp2221_start_read( dev, sla, buf, sizeof(buf), 1 );
	for (i=0; i<got; i++) {
		printf("r[%2i]: 0x%02x\n", i, buf[i]);
	}

	for ( j = 0; j < sizeof(slas)/sizeof(slas[0]); j++ ) {
		set_led_ctl( dev, slas[j], 0x0000 );
		set_led( dev, slas[j], -1, 0x40, 0x60 );
	}

	for ( j = 0; j < sizeof(slas)/sizeof(slas[0]); j++ ) {
		mcp2221_start_write( dev, slas[j], &addr, 1, 0 );
		got = mcp2221_start_read( dev, slas[j], buf, sizeof(buf), 1 );
		for (i=0; i<got; i++) {
			printf("r[%2i]: 0x%02x\n", i, buf[i]);
		}

		for ( i = 0; i < 16; i++ ) {
			set_led_ctl( dev, slas[j], (1<<i) );
			wai.tv_sec  = 0;
			wai.tv_nsec = 500000000;
			nanosleep( &wai, 0 );
		}
		set_led_ctl( dev, slas[j], 0x0000 );
	}

	rval = 0;
bail:
	mcp2221_dev_destroy( dev );
	return rval;
}

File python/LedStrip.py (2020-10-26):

#!/usr/bin/python3

import time
import math

class LedStrip:
  def __init__(self, i2c, i2cAddrLeft = 0x69, i2cAddrRight = 0x05, nLeds=30):
    self.i2cAddrRight_ = i2cAddrRight
    self.i2cAddrLeft_  = i2cAddrLeft
    self.nLeds_        = nLeds
    self.i2c_          = i2c
    self.ctlLeft_      = bytearray(4)
    self.ctlRight_     = bytearray(4)
    self.i2c_.setOffsetAndRead(self.i2cAddrRight_, 0x82, self.ctlRight_)
    self.i2c_.setOffsetAndRead(self.i2cAddrLeft_ , 0x82, self.ctlLeft_ )
    self.ctlLeft_.insert(0, 0x82)
    self.ctlRight_.insert(0, 0x82)

  def setPwmIref(self, pwm, iref = None):
    if pwm is None:
      if iref is None:
        return
      h   = bytearray([0x98])
      pwm = bytearray()
    else:
      h   = bytearray([0x88])
      try:
        if 0 == len(pwm):
          h   = bytearray([0x98])
        elif self.nLeds_ != len(pwm):
          raise RuntimeError("LedStrip.setPwmIref(): invalid pwm arg (must have {:d} elements)".format(self.nLeds_))
      except TypeError:
        pwm = [pwm for i in range(self.nLeds_)]
      pwm = bytearray( pwm )
    if iref is None:
      iref = bytearray()
    else:
      try:
        if self.nLeds_ != len(iref) and 0 != len(iref):
          raise RuntimeError("LedStrip.setPwmIref(): invalid iref arg (must have {:d} elements)".format(self.nLeds_))
      except TypeError:
        iref = [iref for i in range(self.nLeds_)]
      iref = bytearray(iref)
    if self.nLeds_ <= 16:
      if len(pwm) > 0:
        pwm.extend([0 for i in range(16 - self.nLeds_)])
      self.i2c_.drain()
      self.i2c_.sendStartWrite( self.i2cAddrRight_, h + pwm + iref )
    else:
      if len(pwm) > 0:
        pwm.extend([0 for i in range(32 - self.nLeds_)])
      self.i2c_.drain()
      self.i2c_.sendStartWrite( self.i2cAddrRight_, h + pwm[ 0:16] + iref[0 :16         ], sendStop=False )
      self.i2c_.drain()
      self.i2c_.sendStartWrite( self.i2cAddrLeft_ , h + pwm[16:32] + iref[16:self.nLeds_], restart=True )

  @staticmethod
  def _getIdxShft(i):
    idx = int(i/4) + 1
    shf = 2*(i&3)
    return idx,shf

  def setCtrl(self, ctrl):
    for i in range(16):
      idx,shf = self._getIdxShft(i)
      self.ctlRight_[ idx] &= ~(3 << shf)
      self.ctlLeft_ [ idx] &= ~(3 << shf)
      if ( ctrl & (1<<i) ):
        self.ctlRight_[ idx ] |= (2 << shf)
      if ( ctrl & (1<<(i+16)) ):
        self.ctlLeft_ [ idx ] |= (2 << shf)
    self.i2c_.drain()
    self.i2c_.sendStartWrite(self.i2cAddrRight_, self.ctlRight_, sendStop=False)
    self.i2c_.drain()
    self.i2c_.sendStartWrite(self.i2cAddrLeft_ , self.ctlLeft_ , restart =True )

  def flipCtrl(self, bitNo, op = 0):
    if bitNo > 16:
      a = self.i2cAddrLeft_
      c = self.ctlLeft_
      i = bitNo - 16
    else:
      a = self.i2cAddrRight_
      c = self.ctlRight_
      i = bitNo
    idx,shf = self._getIdxShft(i)
    v = c[idx]
    if ( op != 0 ):
      v &= ~(3 << shf)
      if ( op > 0 ):
        v |= (2 << shf)
    else:
      v ^= (2<<shf)
    c[idx] = v
    self.i2c_.drain()
    self.i2c_.sendStartWrite(a, c)

  def grayCount(self, n, sleepTime=0.5):
    self.setCtrl(0)
    lastGray = 0
    for i in range(1,n):
      newGray = i ^ (i>>1)
      bitNo   = int(math.log2(newGray^lastGray))
      self.flipCtrl( bitNo )
      time.sleep(sleepTime)
      lastGray = newGray

  def test(self, termCount = (1<<16), sleepTime=0.01):
    self.setCtrl(0xffffffff)
    for i in range(0xa0):
      self.setPwmIref( 0xff, i )
      time.sleep(0.01)
    for i in range(0xf0, -1, -1):
      self.setPwmIref( i, 0xa0 )
      time.sleep(0.01)
    self.setPwmIref(0x60, 0xc0)
    for i in range(2):
      self.setCtrl(0x55555555)
      time.sleep(3.0)
      self.setCtrl(0xaaaaaaaa)
      time.sleep(3.0)
    self.grayCount( termCount, sleepTime )
    

if "__main__" == __name__:
  from Mcp2221I2c import Mcp2221I2c
  import usb1
  with usb1.USBContext() as ctx:
    mcp = Mcp2221I2c( ctx )
    led = LedStrip(mcp)
    led.test((1<<30))

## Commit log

2020-10-08 renamed mcp2221_i2c.py -> Mcp2221I2c,py; added LedStrip.py
2020-10-08 LedStrip.py: setPwmIref() accepts arrays/collections
2020-10-15 Changed 'drain'; support restart+write; ensure device is drained before sending new read/write commands
2020-10-20 i2ctb.vhd: added test bed
2020-10-20 i2ctb.vhd: added several helper procedures
2020-10-21 Added LedStripController.vhd
2020-10-21 - added i2cRegSlaveWrap.vhd for testing
2020-10-21 Added LedStripMmioWrapper.vhd
2020-10-22 LedStripMmioWrapper.vhd: vivado packager didn't grok to_unsigned in generic default assignment
2020-10-22 LedStripMmioWrapper.vhd: removed unused signal that was set but not declared
2020-10-22 LedStripMmioWrapper.vhd: needed another work-around to make the vivado packager happy :-(
    It cannot understand BLAH := "1" & "1100"; (concatenation)!
2020-10-22 LedStripController.vhd: added comment
2020-10-23 LedStripMmioWrapper.vhd: enable gray-code by default in control-register
2020-10-26 Added kicad design files to git
    [ledstrip.kicad_pcb, ledstrip.sch]
2020-10-26 Added kicad/README.errata file
2020-10-28 LedStripController.vhd: read-back and verify PID data; keep error counters
    Also updated test-beds.
2020-10-28 LedStripMmioWrapper.vhd: vivado IP packager doesn't support real generics
    Work-around by using integers...
2020-10-28 LedStripMmioWrapper.vhd: added support for marker LEDs
2020-10-28 LedStripTcsrWrapper.vhd: must gray-encode upstream of setting marker LEDs
2020-10-28 LedStripTcsrWrapper.vhd: added mux for selecting an update-trigger.
2020-10-28 LedStripTcsrWrapper.vhd: synchronize mux into EVR clock domain.
2020-10-28 LedStripTcsrWrapper.vhd: created block (help naming stuff in ucf files)
2020-10-28 LedStripTcsrWrapper.vhd: made default SCL freq. a generic
2020-10-29 Redrew HFBR component graphics (had rendered badly in PDF)
    [ledstrip.sch]
2020-10-29 ledstrip.sch: added some comments
    [ledstrip.sch]
2020-10-29 added PDF of schematics
2020-10-29 Revert watchdog addition; LedStripController strobe may be decimated
2020-10-29 LedStripTcsrWrapper.vhd: added synError and watchdog error counters
2020-10-29 LedStripMmioWrapper.vhd: adapted tcsrADD width (which has changed)
2020-10-29 LedStripMmioWrapper.vhd: must rearrange local regs
2020-10-29 LedStripTcsrWrapper.vhd: added missing ';'
2020-11-09 Renamed LedStripTcsrWrapperPkg -> Evr320StreamPkg
    The definitions in this package have nothing to do with the LedStrip...
2020-11-09 Fixed PulseIDExtractor (seq errors, pidCount)
    Must check seq errors independently of trigger (decimated
    IDs are not sequential).
    For pidCount count the number of watchdog strobes; this is more
    valuable in case you want to debug trigger problems...
2020-11-09 Added LedStripTmemWrapper.vhd (moved some declarations to LedStripWrapperPkg)
2020-11-10 PulseidExtractor.vhd: bugfixes
    - must check sequence of pulse-ids on every update, not just when
    trigger is set. If the trigger is used to decimate IDs then the
    previous method would flag sequence errors when there were none.
    - increment pulse ID (statistics) counter on every arriving new
    PID. This is more useful than counting triggers (which is equivalent
    with the PID itself). Allows for diagnosing problems with the
    trigger...
2020-11-10 LedStripTmemWrapper.vhd: FIX: write loop accessed 5 byte lanes instead of 4
2021-02-18 LedStripTmemWrapper.vhd: BUGFIX: must check IF_ENA when writing!
